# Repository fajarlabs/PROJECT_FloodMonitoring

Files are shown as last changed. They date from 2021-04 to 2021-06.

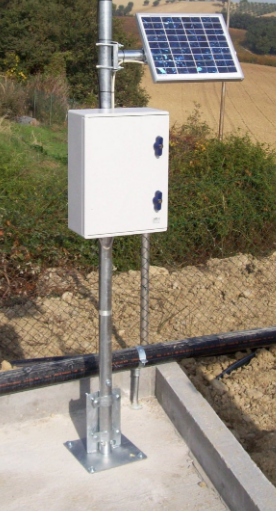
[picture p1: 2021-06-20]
custom.png

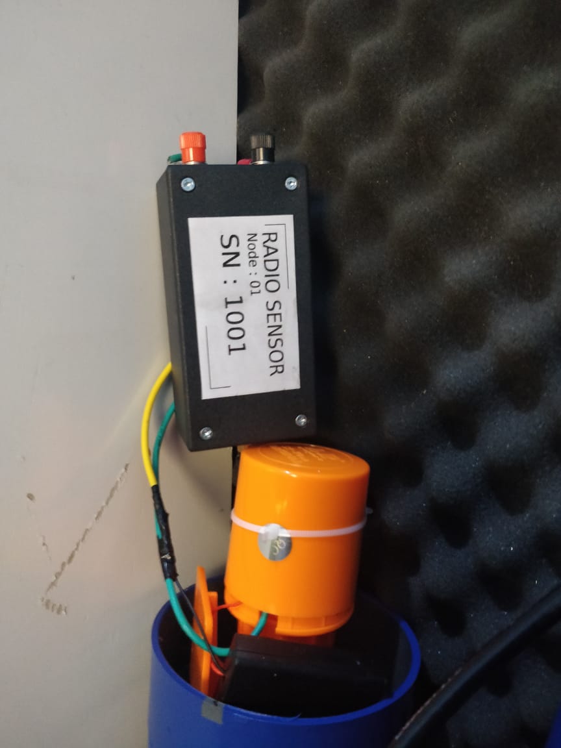
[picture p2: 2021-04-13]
WhatsApp Image 2021-04-13 at 6.48.35 PM.jpeg

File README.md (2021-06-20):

# Project01
The project made a simple flood monitoring system using a buoy sensor and radio nrf24l01
  
# Diagram
signal

# Raspberry PI<br />
Scan IP pakai "advanced ip Scanner" atau tools scan lainnya untuk mencari IP dari raspberry pi<br />
Lalu silahkan masuk melalui SSH / putty<br />
<b>SSH</b></br>
User : pi<br />
Pass : raspberry<br />
Cara masuk ssh, buka cmd lalu ketikkan ````` ssh pi@xxx.xxx.xxx.xxx ````` lalu masukkan passwordnya<br />
Lokasi script python ada di direktori : ````` /home/pi/Documents ````` <br />
<a href="https://imgbb.com/">PATH-FILE-SCRIPT-PYTHON</a><br />
Cara menjalankan script ptyhonnya secara manual seperti berikut ini : <br />````` pi@raspberrypi:~/Documents $ python3 piGateway.py ````` <br />
Untuk autoRUN script agar ketika restart raspberrypi-nya bisa langsung aktif menggunakan PM2<br />
Cara menjalankannya perintahnya berikut ini :  <br />````` pm2 start 0  ````` <br />dan untuk mematikan autoRUNnya bisa menggunakan perintah ini : <br />````` pm2 stop 0  ````` <br />
# Serial<br />
<h2>Receive data from Serial Data</h2>

Dibawah ini adalah bentuk format serial data yang diterima dari radio<br />
`````<<DATA[SN]~[REQ]~[[DATA1]$[DATA2]$[DATA3]...>>`````<br />
Format data seperti dibawah ini : <br />
<b>SN</b> : Serial number atau NODE radio <br />
<b>REQ</b> : Adalah mode yang di kirim ke node lain, ini harus di sesuikan dengan coding mode di alatnya <br />
<b>DATA</b> : Berisi multi data yang di pisahkan / delimiter dengan karakter '$' / dolar <br />
<a href="https://imgbb.com/"><img src="https://i.ibb.co/pJrTyk9/Result-All-Data.png" alt="Result-All-Data" border="0"></a>

<h2>Command Data Format</h2>

`````<<CMD[node]~[req]~[data]>>`````<br />
<b>NODE</b> : Serial number atau NODE radio <br />
<b>REQ</b> : Adalah mode yang di kirim ke node lain, ini harus di sesuikan dengan coding mode di alatnya <br />
<b>DATA</b> : request / command tanpa berisi delimiter '$' dolar hanya data bertipe unsigned-long <br />

<h2>Contoh Perintah</h2>

`````<<CMD02~0~0>>````` <-------- perintah untuk testping serial untuk menyalakan buzzer<br />
Apabila untuk transmit ke node lain perintah yang diubah adalah nodenya, contonya seperti ini : <br />
`````<<CMD02~1~1>>````` <-------- perintah untuk mengirimkan pesan ke node02 melalu NRF radio<br />

Contoh perintah untuk mematikan untuk menghidupkan relay panel<br />
`````<<CMD02~1~1>>````` <----- ON <br />
`````<<CMD02~1~2>>````` <----- OFF<br />

<h2>Check ports</h2><br />
<a href="https://ibb.co/YyH0wQB"><img src="https://i.ibb.co/b2cbDm5/Whats-App-Image-2021-04-14-at-7-31-27-AM.jpg" alt="Whats-App-Image-2021-04-14-at-7-31-27-AM" border="0"></a><br />
<a href="https://imgbb.com/"><img src="https://i.ibb.co/P9nCbmL/PORT-LIST.png" alt="PORT-LIST" border="0"></a><br />
Port yang di pakai di raspberrypi gateway : <br />
<b>Port : /dev/ttyUSB0</b> <br />
<b>Baud Rate : 9600</b> <br /><br />

<h2>Records DB (PostgreSQL)</h2>
<a href="https://ibb.co/zH8crwm"><img src="https://i.ibb.co/fG8R27X/data-Record.png" alt="data-Record" border="0"></a><br />
<h2>Commands on table "nodes_cmd"</h2>
<a href="https://imgbb.com/"><img src="https://i.ibb.co/9Vf42ZB/Command-Push.png" alt="Command-Push" border="0"></a><br />
<h2>Log Panel Controller</h2>
<a href="https://ibb.co/3dY326t"><img src="https://i.ibb.co/KhzPd4C/data-Log-Controller.png" alt="data-Log-Controller" border="0"></a>

# Flash FTDI to PROMINI <br />
Sesuaikan pin-pinnya dan tancapkan ke board promininya ke lubang2nya tanpa disolder dan tahan agar socketnya menempel dengan baik <br />
lalu coba buka arduino IDE dan sesuikan PORTnya. Untuk selectornya set ke 5 volt di FTDInya.<br />
<img src="https://www.b4x.com/android/forum/attachments/conexao-ftdi-arduino-pro-mini-jpg.53557/" />

# Sketch Command Center <br />
<a href="https://ibb.co/sbL2gpL"><img src="https://i.ibb.co/q7bdDLb/COMMAND-CENTER-bb.png" alt="COMMAND-CENTER-bb" border="0"></a><br />
# Sketch Float Sensor <br />
<a href="https://ibb.co/3CtSbP8"><img src="https://i.ibb.co/x7Vzbrc/FLOAT-SENSOR.png" alt="FLOAT-SENSOR" border="0"></a><br />
# Sketch Panel Controller <br />
<a href="https://ibb.co/80PH36w"><img src="https://i.ibb.co/jT3SKgY/PANEL-CONTROLLER-bb.png" alt="PANEL-CONTROLLER-bb" border="0"></a><br />

# Box Panel Controller <br />
Lampu indikator ada 3 warna : <br />
<b>Warna Merah</b> : Kontaktor dalam keadaan OFF / kontaktor tidak terhubung <br />
<b>Warna Kuning</b> : Power Supply OK </br>
<b>Warna Hijau</b> : Kontaktor dalam keadaan ON atau generator dalam keadaan starting-up / aktif<br /><br />
<a href="https://ibb.co/4SdvPH1"><img src="https://i.ibb.co/ykSvWr4/Whats-App-Image-2021-04-14-at-7-13-49-AM.jpg" alt="Whats-App-Image-2021-04-14-at-7-13-49-AM" border="0"></a>
<img src="https://i.ibb.co/tzzwFxp/BOX-PANEL-FLASH.jpg" />
<img src="https://i.ibb.co/HXfv78d/BOX-PANEL2.jpg" />

# Float Sensor
<img src="https://i.ibb.co/J73hCQb/SENSOR-FLOAT.jpg" />
<img src="https://i.ibb.co/Tvc8hM1/SENSOR-FLOAT2.jpg" />
<img src="https://i.ibb.co/Tvc8hM1/SENSOR-FLOAT2.jpg" />
<img src="https://i.ibb.co/P68yMzF/SENSOR-FLOAT4.jpg" />
<img src="https://i.ibb.co/pXg9CGh/SENSOR-FLOAT5.jpg" />

# Sensor solar 
Untuk cek ketersediaan bbm, bukan volume karena bukan tipe analog karena harganya perCM cukup mahal dan perlu kalibrasi dengan panjang, lebar, tinggi<br />
<a href="https://ibb.co/xgt35PT"><img src="https://i.ibb.co/7pdby8m/Whats-App-Image-2021-04-11-at-10-44-52-PM.jpg" alt="Whats-App-Image-2021-04-11-at-10-44-52-PM" border="0"></a>
<a href="https://ibb.co/Pr9xSyZ"><img src="https://i.ibb.co/ZfYdZr6/Whats-App-Image-2021-04-11-at-10-45-48-PM.jpg" alt="Whats-App-Image-2021-04-11-at-10-45-48-PM" border="0"></a>
<a href="https://ibb.co/q9xj9Hf"><img src="https://i.ibb.co/K7mh7tk/Whats-App-Image-2021-04-11-at-10-45-41-PM.jpg" alt="Whats-App-Image-2021-04-11-at-10-45-41-PM" border="0"></a>

# Core control RS232 
Retrieve dan command dari sini <br />
<a href="https://ibb.co/fx5VGBT"><img src="https://i.ibb.co/XCgfkNG/Whats-App-Image-2021-04-11-at-10-38-35-PM.jpg" alt="Whats-App-Image-2021-04-11-at-10-38-35-PM" border="0"></a>

<a href="https://ibb.co/R9BkKkW"><img src="https://i.ibb.co/VtQcGc8/Whats-App-Image-2021-04-12-at-12-04-18-AM.jpg" alt="Whats-App-Image-2021-04-12-at-12-04-18-AM" border="0"></a>

<a href="https://ibb.co/0DzcRdz"><img src="https://i.ibb.co/K08Xp38/Whats-App-Image-2021-04-13-at-5-51-59-PM.jpg" alt="Whats-App-Image-2021-04-13-at-5-51-59-PM" border="0"></a><br />

<a href="https://ibb.co/DgNR2WH"><img src="https://i.ibb.co/QjZKwQ3/Whats-App-Image-2021-04-13-at-5-54-51-PM.jpg" alt="Whats-App-Image-2021-04-13-at-5-54-51-PM" border="0"></a><br />

<a href="https://ibb.co/h1q2V0N"><img src="https://i.ibb.co/M5XP7dH/Whats-App-Image-2021-04-13-at-6-48-35-PM.jpg" alt="Whats-App-Image-2021-04-13-at-6-48-35-PM" border="0"></a><br />

<h2> Cara mencopot pipa untuk setup ketinggian level airnya</h2>
<a href="https://ibb.co/zmyzbyr"><img src="https://i.ibb.co/Jcf92fK/Whats-App-Image-2021-04-14-at-7-35-01-AM.jpg" alt="Whats-App-Image-2021-04-14-at-7-35-01-AM" border="0"></a>
<a href="https://ibb.co/1ZxKc63"><img src="https://i.ibb.co/31HWKzw/Whats-App-Image-2021-04-14-at-7-33-16-AM.jpg" alt="Whats-App-Image-2021-04-14-at-7-33-16-AM" border="0"></a>
<a href="https://ibb.co/bJRhJFB"><img src="https://i.ibb.co/HdpvdCz/Whats-App-Image-2021-04-14-at-7-28-10-AM.jpg" alt="Whats-App-Image-2021-04-14-at-7-28-10-AM" border="0"></a>
<a href="https://ibb.co/Jsb5nLQ"><img src="https://i.ibb.co/rwL4kPs/Whats-App-Image-2021-04-14-at-7-26-18-AM.jpg" alt="Whats-App-Image-2021-04-14-at-7-26-18-AM" border="0"></a>
<a href="https://ibb.co/mtGvR3R"><img src="https://i.ibb.co/Bjt4f9f/Whats-App-Image-2021-04-14-at-7-24-02-AM.jpg" alt="Whats-App-Image-2021-04-14-at-7-24-02-AM" border="0"></a>

<h2> Cara lepas untuk setup pelampung </h2>
<a href="https://ibb.co/Rpw31Mp"><img src="https://i.ibb.co/qMQNz4M/Whats-App-Image-2021-04-14-at-7-18-26-AM.jpg" alt="Whats-App-Image-2021-04-14-at-7-18-26-AM" border="0"></a>
<a href="https://ibb.co/GCVyGZR"><img src="https://i.ibb.co/kqhjzLX/Whats-App-Image-2021-04-14-at-7-18-06-AM.jpg" alt="Whats-App-Image-2021-04-14-at-7-18-06-AM" border="0"></a>

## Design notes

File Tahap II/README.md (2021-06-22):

# Project01 - Development Tahap II
The project made a simple flood monitoring system using a buoy sensor, rain-gauge and radio nrf24l01

# Sumber Kode
Didalam folder tahap II ini terdapat folder script diantaranya, <br />
1.) <b>piGateway</b> : Berisi script python yang dijalankan di raspberry gateway <br />
2.) <b>SubscriberMQTT</b> : Berisi script python yg dijalankan disisi server untuk menerima raw data yang dikirim / dibroadcast untuk raspberrypi gateway<br />
3.) <b>TRANSMIT_FLOOD_SENSOR</b> : Berisi script untuk arduino <br />

# FLASH IC ATMEGA328
Menggunakan USB ASP + ZIP Socket <br />
<a href="https://imgbb.com/">USB-ASP</a> <br />

Untuk librarynya menggunakan "MiniCore" <br />
Untuk repositorynya ada disini : <b><a href="https://github.com/MCUdude/MiniCore">MiniCore</a></b> <br />

# Raspberry PI<br />
Bukan terminal dan tambahkan library paho.mqtt dengan mengetik <br />
````` pip install paho-mqtt ````` <br />
Untuk scriptnya di override dari script yang sebelumnya menggunakan piGateway yang didalam folder Tahap II <br />
Sebelum menjalankan scriptnya ubah terlebih dahulu account mqtt account disesuaikan dengan server broker yang sudah dibuat sebelumnya. <br />
<a href="https://ibb.co/d7ZqTfV"><img src="https://i.ibb.co/R78mFgs/Edit-Account-MQTT.png" alt="Edit-Account-MQTT" border="0"></a>
<br />
Untuk menjalankannya silahkan ketik pada terminal perintah berikut ini : <br />
````` python piGateway.py ````` <br />

Untuk menjalankan script program untuk subscriber MQTT dan parsing ada didalam folder SubscriberMQTT. Edit account MQTT sesuai server broker yang telah dibuat.<br />
Didalam script subscriber MQTT ini hanya sampai dengan parsing saja, tidak sampai untuk insert ke dalam database. <br />

Untuk menjalankan program ketikan di terminal / command prompt perintah berikut : <br />
````` python subscriberData.py ````` <br />

Untuk format data yang dikirim lewat MQTT berbentuk RAW, dan diparsing didalam script subscriberData.py <br />
<a href="https://ibb.co/tM6VV2m"><img src="https://i.ibb.co/DDF00MV/Format-Code.png" alt="Format-Code" border="0"></a> <br />

Untuk instalasi mosquitto-clients di linux ubuntu seperti berikut ini : <br />
````` sudo apt-get install mosquitto-clients `````

Untuk perintah testing mqtt tanpa script juga bisa dilakukan dengan mengetik perintah : <br />
<a href="https://ibb.co/FBj3fby"><img src="https://i.ibb.co/4j5tDZX/mosquitto-sub.png" alt="mosquitto-sub" border="0"></a><br />
````` mosquitto_sub -h test.mosquitto.org -t "/mytopic/raw_data" -v ````` <br />

Untuk screenshot hasil test seperti berikut ini : <br />
Debug MQTT <br />
<a href="https://ibb.co/vJM7yxg"><img src="https://i.ibb.co/K98M4jR/Debug-MQTT.png" alt="Debug-MQTT" border="0"></a> <br />
Debug di Gateway <br />
<a href="https://ibb.co/WtbXbgG"><img src="https://i.ibb.co/0tgLghm/TRANSMIT-DATA-GTW.png" alt="TRANSMIT-DATA-GTW" border="0"></a> <br />

Untuk IC menggunakan ATMEGA328 dengan keterangan pinout dibawah ini (<b> Warna Biru </b> ) : <br />
<a href="https://ibb.co/nCmdzjr"><img src="https://i.ibb.co/4dtvPpW/68747470733a2f2f692e696d6775722e636f6d2f715849456368542e6a7067.jpg" alt="68747470733a2f2f692e696d6775722e636f6d2f715849456368542e6a7067" border="0"></a><br /><a target='_blank' href='https://id.imgbb.com/'>gambum</a><br /><br />
Pin yang digunakan untuk proyek ini sebagai berikut ini : <br />

# NRF PIN
Pin untuk NRF (warna biru) <br />
<b>Pin 7 </b> : CE <br />
<b>Pin 8 </b> : CSN <br />
<b>Pin 11</b> : MISO <br />
<b>Pin 12</b> : MOSI <br />
<b>Pin 13</b> : SCK <br />

# RAIN GAUGE PIN
Pin untuk <i>rain gauge sensor</i> pada <b>Pin 6</b>

# INPUT WATER LEVEL
L4 : PIN 6<br />
L3 : PIN 4<br /> 
L2 : PIN 3<br />
L1 : PIN 2<br />

# OUTPUT RELAY TRIGGER
OUTPUT4 : PIN 12 <b>Optional, if not using NRF module</b><br />
OUTPUT3 : PIN 11 <b>Optional, if not using NRF module</b><br />
OUTPUT2 : PIN 10 <b>Not used</b><br />
OUTPUT1 : PIN 9 <b>Not used</b><br />

Untuk desain PCB menggunakan sprintlayout dan sudah terlampir di dalam folder Tahap II dengan nama file PCB_Interface.lay <br />
Gambar PCB seperti berikut ini: <br />
<a href="https://ibb.co/d2hWskj"><img src="https://i.ibb.co/WyTxNBG/PCB-Interface.jpg" alt="PCB-Interface" border="0"></a><br />

Galeri proyek : <br />
<a href="https://ibb.co/zfkCwdP"><img src="https://i.ibb.co/cTmRdq2/Whats-App-Image-2021-06-20-at-11-57-32-PM-1.jpg" alt="Whats-App-Image-2021-06-20-at-11-57-32-PM-1" border="0"></a><br />
<a href="https://ibb.co/4Vt1FCm"><img src="https://i.ibb.co/nLmPw4g/Whats-App-Image-2021-06-20-at-11-57-32-PM-2.jpg" alt="Whats-App-Image-2021-06-20-at-11-57-32-PM-2" border="0"></a><br />
<a href="https://ibb.co/3zZNfRB"><img src="https://i.ibb.co/GTS2sHc/Whats-App-Image-2021-06-20-at-11-57-32-PM-4.jpg" alt="Whats-App-Image-2021-06-20-at-11-57-32-PM-4" border="0"></a><br />

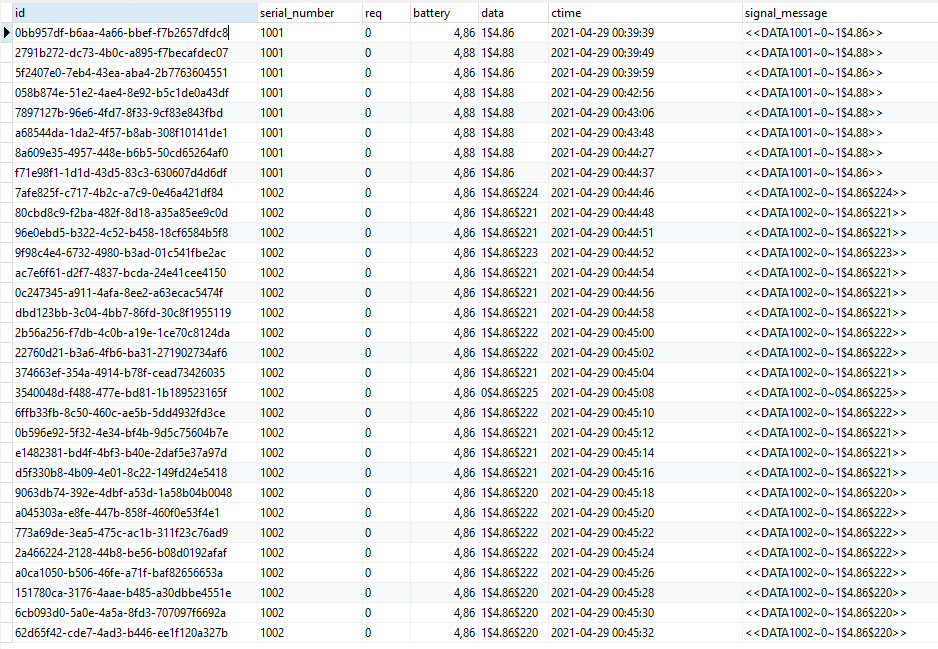
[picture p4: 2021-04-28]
dataRecord.png

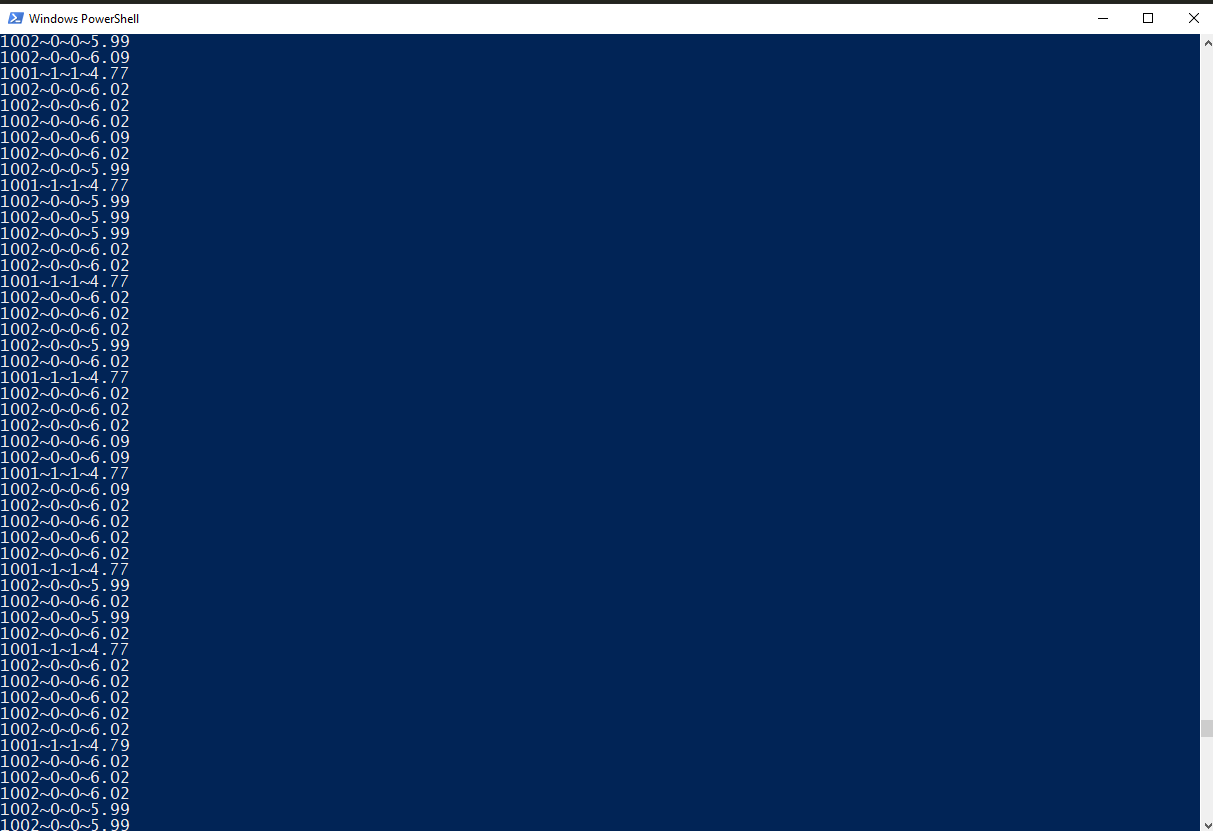
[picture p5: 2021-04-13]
python.png

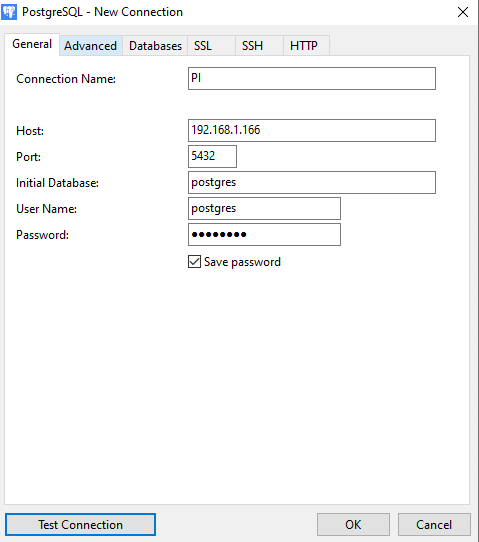
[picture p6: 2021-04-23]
LOGIN_DB.png

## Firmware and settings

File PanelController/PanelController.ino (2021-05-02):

#include <SPI.h>
#include <RF24.h>
#include <RF24Network.h>
#define RELAYPIN 9
#define FUELPIN 6
#define CMD 0
#define SERIAL_NUMBER 1002
#include <Filters.h>
#define voltageSensorPin A0 // input voltage sensor
#define voltageDCSensorPin A1
#include <Wire.h> 
#include <LiquidCrystal_I2C.h>
LiquidCrystal_I2C lcd(0x27,20,4);  // set the LCD address to 0x27 for a 16 chars and 2 line display

float testFrequency = 50; // Standard current freqwensi indonesia (Hz)
float windowLength = 40.0/testFrequency;    
float intercept = -0.04;
float slope = 0.0405;
float volts; // data voltage
unsigned long voltCheckPeriode = 1000; 
unsigned long voltCurTime = 0;
RunningStatistics inputStats;   // init statistic

// Floats for ADC voltage & Input voltage
float adc_voltage = 0.0;
float in_voltage = 0.0;
// Floats for resistor values in divider (in ohms)
float R1 = 30000.0;
float R2 = 7500.0; 
// Float for Reference Voltage
float ref_voltage = 5.0;
// Integer for ADC value
int adc_value = 0;

RF24 radio(7, 8);               // nRF24L01(+) radio attached using Getting Started board

RF24Network network(radio);     // Network uses that radio
const uint16_t this_node = 02;  // Address of our node in Octal format (04, 031, etc)
const uint16_t node01 = 00;    // Address of the other node in Octal format

const unsigned long interval = 2000; // How often (in ms) to send 'hello world' to the other unit
unsigned long last_sent;             // When did we last send?

struct payload_t { 
  unsigned long sn;
  unsigned long req;   
  char data[25];
};

struct command_t {
  uint16_t node;
  unsigned long req;
  unsigned long data;
};

typedef struct global_t {
  bool isRelayON = false;
} Global;

Global global; 

void setup(void) {
  inputStats.setWindowSecs(windowLength);
  pinMode(RELAYPIN, OUTPUT); // relay for trigger
  pinMode(FUELPIN, INPUT);   // fuel input
  Serial.begin(9600);
  if (!Serial) {
    // some boards need this because of native USB capability
  }
  Serial.println(F("<<ControllerON>"));

  SPI.begin();
  if (!radio.begin()) {
    Serial.println(F("Radio hardware not responding!"));
    while (1) {
      // hold in infinite loop
    }
  }
  network.begin(/*channel*/ 90, /*node address*/ this_node);
}

void loop(void) {
  network.update();                  // Check the network regularly
  unsigned long now = millis();
  inputStats.input(analogRead(voltageSensorPin));

  if((unsigned long)(millis() - voltCurTime) >= voltCheckPeriode) {   
    // Alternating Current Voltage Data
    volts = intercept + slope * inputStats.sigma(); //offset y amplitud
    volts = volts*(40.3231); 
    voltCurTime = millis(); 
    
    // Directing current Voltage data
    adc_value = analogRead(voltageDCSensorPin);
    // Determine voltage at ADC input
    adc_voltage  = (adc_value * ref_voltage) / 1024.0; 
    // Calculate voltage at divider input
    in_voltage = adc_voltage / (R2/(R1+R2)); 
  }
  
  //===== Receiving =====//
  while (network.available()) {      // Is there anything ready for us?
    RF24NetworkHeader header;        // If so, grab it and print it out
    command_t cmd_payload;
    network.read(header, &cmd_payload, sizeof(cmd_payload));
    /*
    Serial.println("Received packet #");
    Serial.println(cmd_payload.node);
    Serial.println(cmd_payload.req);
    Serial.println(cmd_payload.data);
    */
    if(cmd_payload.req == 1){
      if(cmd_payload.data == 1) {
        Serial.println("<<TriggerON>>");
        digitalWrite(RELAYPIN, HIGH);
        global.isRelayON = true;
      }
      if(cmd_payload.data == 2) {
        Serial.println("<<TriggerOFF>>");
        digitalWrite(RELAYPIN, LOW);
        global.isRelayON = false;
      }
    }
  }

  if(global.isRelayON)
    digitalWrite(RELAYPIN, HIGH);
  else
    digitalWrite(RELAYPIN, LOW);

  //===== Sending =====//
  // if request == 1 is transmit 
  if (now - last_sent >= interval) {
    last_sent = now;

    //============================================================================
    // Fuel data
    //============================================================================
    int fuelExist = 0;
    if(digitalRead(FUELPIN) == HIGH) fuelExist = 1;

    //============================================================================
    // Module voltage
    //============================================================================
    double curvolt = double( readVcc() ) / 1000; // (current module voltage DC)
    
    //============================================================================
    // AC voltage sensor
    //============================================================================
    // AC voltage variable
    char curACStr[4];
    // format float 
    dtostrf(volts, 3, 0, curACStr);

    //============================================================================
    // Concat data using delimiter '$'
    //============================================================================
    String data = String(fuelExist);
    data += "$";
    data += String(curvolt);
    data += "$";
    data += String(curACStr);
    data += "$";
    data += String(in_voltage);
    char datachar[data.length()+1];
    data.toCharArray(datachar,data.length()+1);
    // payload
    payload_t payload2 = { SERIAL_NUMBER, CMD, curvolt };
    // bind to struct (AC voltage)
    strncpy(payload2.data, datachar, sizeof(payload2.data) - 1);
    
    RF24NetworkHeader header2(node01);     // (Address where the data is going)
    if(network.write(header2, &payload2, sizeof(payload2))) {
      Serial.println("<<Transmit>>");
    } else {
      Serial.println("<<Failed>>");
    }
  }
}

//read internal voltage
long readVcc() {
  long result;
  // Read 1.1V reference against AVcc
  ADMUX = _BV(REFS0) | _BV(MUX3) | _BV(MUX2) | _BV(MUX1);
  delay(2); // Wait for Vref to settle
  ADCSRA |= _BV(ADSC); // Convert
  while (bit_is_set(ADCSRA, ADSC));
  result = ADCL;
  result |= ADCH << 8;
  result = 1126400L / result; // Back-calculate AVcc in mV
  return result;
}

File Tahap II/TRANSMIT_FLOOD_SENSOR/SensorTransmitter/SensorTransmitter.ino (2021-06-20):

#include <SPI.h>
#include <RF24.h>
#include <RF24Network.h>

#define SERIAL_NUMBER 1001
#define CMD 0                        // do something with command
#define BUZZER A5
#define INPUT4 6
#define INPUT3 4  
#define INPUT2 3
#define INPUT1 2
#define OUTPUT2 10
#define OUTPUT1 9
#define RAIN_GAUGE 5

int is_beep = 0;
int levelFlood = 0;

int rainInTick = 0;
bool bucketPositionA = false;  
const double bucketAmount = 0.053;        // 0.053 inches atau 1.346 mm of rain equivalent of ml to trip tipping-bucket
//note:
//diketahui bahwa 1 inchi = 2.54 cm
//diketahui bahwa 1 tip sensor ini = 2.6 mL
//maka 0.053 inchi of rain didapat dari:
//panjang rain collector = 5.4 cm atau 2.126 inchi
//lebar rain collector = 3.6 cm atau 1.417 inchi
//luas=pxl -> 2.16 inchi x 1.417 inchi = 3.012 inchi persegi
//U.S. measures rain in inches so it would be 3.012 inchi kubik
//lalu dikonversi dari inchi kubik mjd mL dan didapat bahwa 3.012 inchi kubik = 49.358 mL
//yg artinya 1 inchi of rain = 49.358 mL
//sehingga 1 tip sensor ini mewakili 2.6 mL/49.358 mL = 0.053 inchi of rain
 
double countRain = 0.0;                // rain accumulated for the day

RF24 radio(7, 8);                    // nRF24L01(+) radio attached using Getting Started board
RF24Network network(radio);          // Network uses that radio

const uint16_t node01 = 00;          // Address of our node in Octal format
const uint16_t this_node = 01;       // Address of the other node in Octal format

const unsigned long interval = 1000; // How often (in ms) to send 'hello world' to the other unit
unsigned long last_sent;             // When did we last send?

unsigned long beep_interval = 500; 
unsigned long beep_last_sent;                      

struct payload_t {                   // Structure of our payload
  unsigned long sn;
  unsigned long req;   
  char data[35];
};

void setup(void) {
  pinMode(RAIN_GAUGE, INPUT);
  pinMode(INPUT1, INPUT);
  pinMode(INPUT2, INPUT);
  pinMode(INPUT3, INPUT);
  pinMode(INPUT4, INPUT);
  pinMode(OUTPUT1, OUTPUT);
  pinMode(OUTPUT2, OUTPUT);
  pinMode(BUZZER, OUTPUT);

  // init beep after boot
  int beep = 0;
  for (int b=0; b<6; b++){
    if(beep < 1) {
      analogWrite(BUZZER, 255);
      beep = 1;
    } else {
      analogWrite(BUZZER, 0);
      beep = 0;
    }
    delay(1000);
  }
  
  Serial.begin(9600);
  if (!Serial) {
    // some boards need this because of native USB capability
  }
  Serial.println("<<SensorON>>");

  SPI.begin();
  if (!radio.begin()) {
    Serial.println(F("Radio hardware not responding!"));
    while (1) {
      // hold in infinite loop
    }
  }
  network.begin(/*channel*/ 90, /*node address*/ this_node);
}

void countLevelFlood() {
   levelFlood = 0; // reset
   if(digitalRead(INPUT1) == LOW) levelFlood++;
   if(digitalRead(INPUT2) == LOW) levelFlood++;
   if(digitalRead(INPUT3) == LOW) levelFlood++;
   if(digitalRead(INPUT4) == LOW) levelFlood++;
}

void loop() {

  countLevelFlood();

  // ======================= Count the bucket tips ================================
  if ((bucketPositionA==false)&&(digitalRead(RAIN_GAUGE)==LOW)){
    bucketPositionA=true;
    countRain+=bucketAmount;                               // update the daily rain
  }
  
  if ((bucketPositionA==true)&&(digitalRead(RAIN_GAUGE)==HIGH)){
    bucketPositionA=false;  
  } 
  // ==============================================================================
  
  network.update(); // Check the network regularly
  unsigned long now = millis();

  if(levelFlood == 1) beep_interval = 2000;
  if(levelFlood == 2) beep_interval = 1500;
  if(levelFlood == 3) beep_interval = 700;
  if(levelFlood == 4) beep_interval = 200;
  if((levelFlood > 0) || (is_beep == 1)){
    // If it's time to send a message, send it!
    if (now - beep_last_sent >= beep_interval) {
      beep_last_sent = now;
      if(is_beep == 0) {
        is_beep = 1;
        analogWrite(BUZZER, 255);
      } else {
        is_beep = 0;
        analogWrite(BUZZER, 0);
      }
    }
  }
  
  // If it's time to send a message, send it!
  if (now - last_sent >= interval) {
    last_sent = now;

    //============================================================================
    // Flood data static
    //============================================================================
    long floatData = 1; // data ON (trigger flood)
    
    //============================================================================
    // Current voltage DC module
    //============================================================================
    double curvolt = double( readVcc() ) / 1000;
    
    //============================================================================
    // Concat data using delimiter '$'
    //============================================================================
    String data = String(floatData);
    data += "$";
    data += String(curvolt);
    data += "$";
    data += String(countRain);
    data += "$";
    data += String(levelFlood);
    char datachar[data.length()+1];
    data.toCharArray(datachar,data.length()+1);
    
    // payload
    payload_t payload2 = { SERIAL_NUMBER, CMD };
    
    // bind to struct (AC voltage)
    strncpy(payload2.data, datachar, sizeof(payload2.data) - 1);
    
    RF24NetworkHeader header(/*to node*/ node01);
    
    if(network.write(header, &payload2, sizeof(payload2))){
      Serial.println("<<TRANSMIT>>");
    } else {
      Serial.println("<<FAILED>>");
    }

    countRain = 0; // reset rain after sending to gateway    
  }
}

//read internal voltage
long readVcc() {
  long result;
  // Read 1.1V reference against AVcc
  ADMUX = _BV(REFS0) | _BV(MUX3) | _BV(MUX2) | _BV(MUX1);
  delay(2); // Wait for Vref to settle
  ADCSRA |= _BV(ADSC); // Convert
  while (bit_is_set(ADCSRA, ADSC));
  result = ADCL;
  result |= ADCH << 8;
  result = 1126400L / result; // Back-calculate AVcc in mV
  return result;
}
